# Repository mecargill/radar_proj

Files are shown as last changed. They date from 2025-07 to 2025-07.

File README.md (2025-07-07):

You can find a description of this radar project on https://mecargill.github.io/portfolio_page/.

Mcu_fmcw_manager is code for an STM32 f446. It buffers data from the ADC and sends it over SPI to the master (a raspberry pi in my case).
It also sends a triangle wave to the DAC.

Fmcw_pcb contains the KiCAD project in which I made the schematic and PCB for the radar.

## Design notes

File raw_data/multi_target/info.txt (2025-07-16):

I first took a baseline for 5s, then took a capture of a static corner reflector for 5s, then took a capture of me and shae moving forward and back at different distances for 25s
Turns out I messed up my pcb and made the data clip, so these data are kinda bad. I fixed it later

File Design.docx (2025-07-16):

# Operation

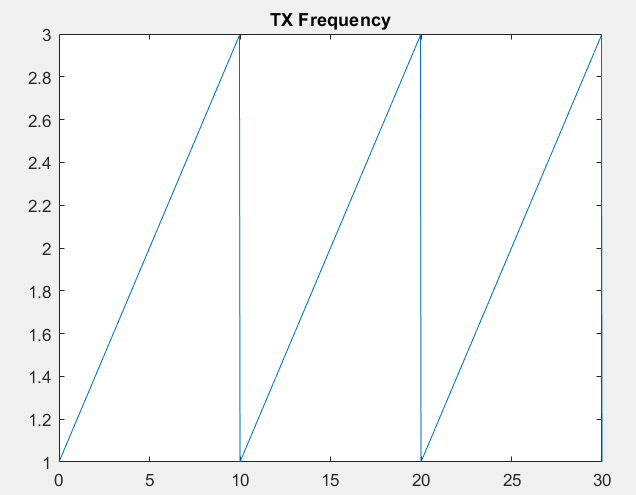
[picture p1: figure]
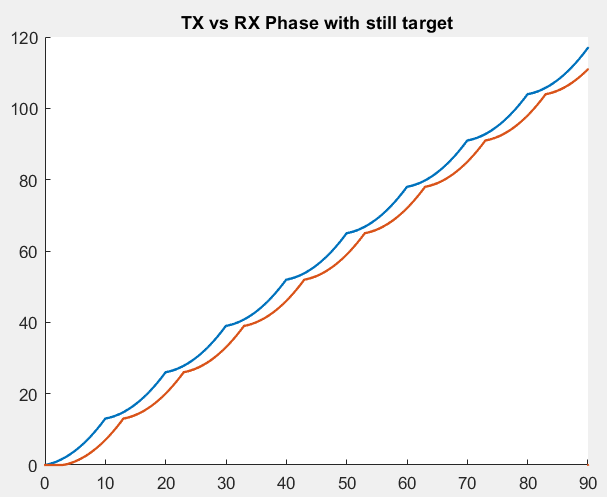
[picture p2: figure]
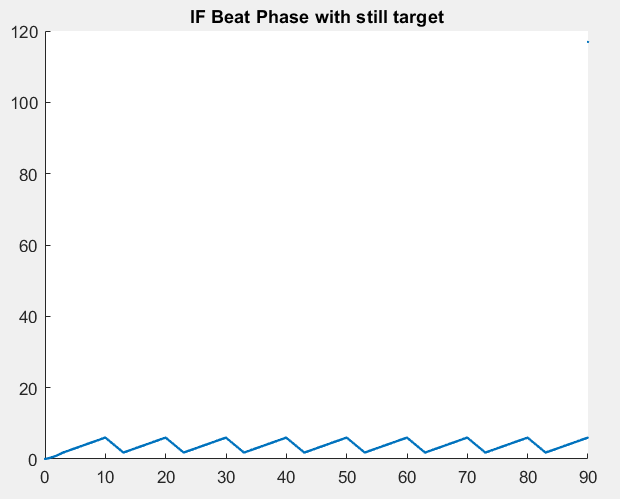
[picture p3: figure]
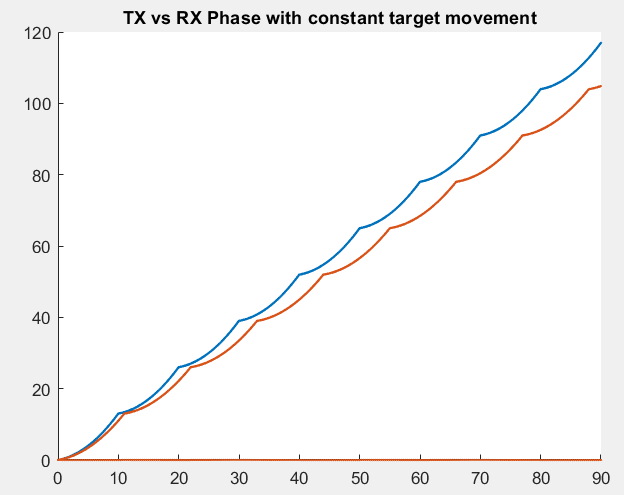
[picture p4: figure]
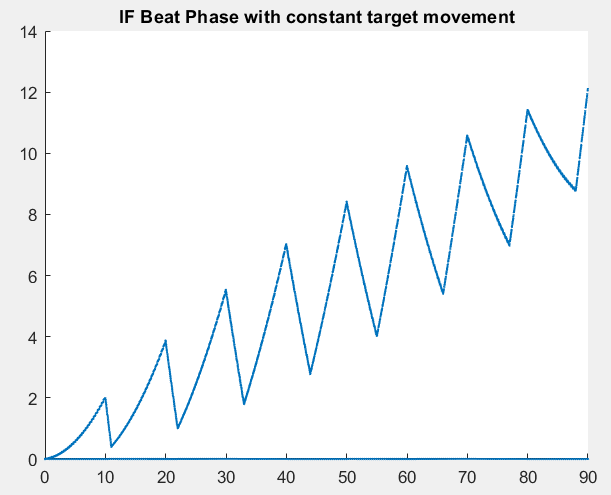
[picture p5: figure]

The TX signal is the scaled integral of the frequency function. The RX signal is a function where at a time t it equals the TX at a time t – d(t) where d(t) is the delay that the signal currently being received had to undergo due to the round trip time. Taking the fft of each cycle gives the slope. Taking the fft of that gives the slope of given points in each cycle, say the bottom, which under certain assumptions is linear (small delays, range is limited anyways).

# Target Specs

- FCC part 15 doesn’t consider CW applications… closest is digital modulation in part 15.247 – max conducted power 1W (30dBm) w max 6dbi antenna gain, so max 36dBm EIRP
- 2400 – 2483.5 GHz ISM band – low regulation, at worst will mess with wifi
- Max 6dbi antenna – keep it directional
- Use microcontroller and DAC (possibly built in) for ramp generation and buffering ADC output
- 500us chirp time, 80MHz sweep
- 10m range in normal operating conditions

# Part Options

1. Microcontroller
  a. STM32F745VGH6
    i. Hopefully this is enough
    ii. Has a couple dacs and adcs and prob enough power for FFT and stuff
  b. STM32H743VGT6
    i. More memory and power
    ii. 15$
  c. St link
    i. https://www.amazon.com/AITRIP-Emulator-Downloader-Programmer-STM32F103C8T6/dp/B0D22S8WVX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
2. DAC
  a. On MCU
3. VCO
  a. Crystek CVCO33BE-2400-2500
    i. 0-3VDC tuning
    ii. 2.4-2.5GHz
    iii. 55MHz/V sensitivity
    iv. +1dBm Typ output power
    v. -116 dBc/Hz at 100kHz offset
    vi. 25$
  b. MAX 2750
    i. 0.4-2.4V tuning
    ii. 2.4-2.5GHz
    iii. ~50MHz/V sensitivity
    iv. -3dBm output
    v. -95dBc/Hz at 100kHz offset
    vi. 9$
4. RF connections for pcb
  a. Sma to nM x2
    i. Cinch Connectivity 29 3840
      1. 9$
    ii. RF Industries RSA 3453 or 3478
      1. 10$
  b. Sma through hole x2
    i. Gradconn RFPC SMA 28 F
      1. 2$
  c. Sma m to m barrel
    i. RF solutions ADP-SMAM-SMAM90
      1. Right angle
      2. $5
5. Splitter
  a. Mini circuits ZX10-2-332-S
    i. 46$ Yikes
  b. BD 2626
    i. $2
  c. Make one yourself
    i. Bunch of resistors and stuff
    ii. 10$?
6. PA
  a. BeRex BG13D
    i. 21.5 dB gain
    ii. P1db 19
    iii. 3$
  b. Skyworks SKY65900-11
    i. 34dB gain
    ii. P1db 34 dBm
    iii. $2.5
7. Antenna
  a. FMANLP1009 x2
    i. 10 dBi gain
    ii. 50 deg beamwidth
    iii. 16$
    iv. Female n connector
  b. Make own
8. LNA
  a. https://www.digikey.com/en/products/filter/rf-amplifiers/860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
  b. Berex BL022A
    i. 17-18.5 dB gain 2.4GHz
    ii. 1.5-1.8 NF 2.4GHz
    iii. 3.50$
  c. Qorvo QPL9504
    i. 20-21dB gain 2.4GHz
    ii. ~0.5dB NF
    iii. No leads
    iv. 5$
9. Mixer
  a. MAX 2680
    i. 3$
    ii. Active -> -10-0 dBm LO input, and >-25dBm RF input
    iii. Not rated to output less than 10MHz
  b. ADL5801ACPZ-R7
    i. 15$
  c. LTC5548IUDB#TRPBF
    i. 25$
  d. TRF3705IRGER
  e. Mini Circuits ADE-3G+
    i. $7
    ii. Requires input and output match
    iii. Requires amplified LO
    iv. Overall an extra amp, attenuator, and matching net
  f. Analog AD8343
    i. $11
    ii. Requires output match
    iii. Active, -10dB LO
10. BPF
  a. Walsin RFBPF1608060AAT
    i. 2.4-2.5GHZ
    ii. Like $1 for all 3
    iii. Very small, like 0.8mm x 1mm
  b. Johansen 2450BP08A0100001T
    i. Same specs
    ii. Slightly bigger
  c. Taoglas DBP.2450.X.A.30
    i. 1 db more IL
    ii. Much bigger, way easier to solder
11. LPF
  a. Make one yourself
    i. Op amp and stuff
    ii. 2$?
12. ADC
  a. On MCU
13. Housing
  a. 3D print or ignore for now…

# Design

To choose the exact output power, we consider that we want as low power as possible (for less heat, oscillation, and saturation risk) while maintaining some amount of range ability. I would like around >=10m of range for a normal target (maybe a car w 10m^2 RCA).

Here, the rows are ranges (1, 5, 10, 15) m, and columns are (1, 10, 40) m^2 RCA. The power levels are conducted.

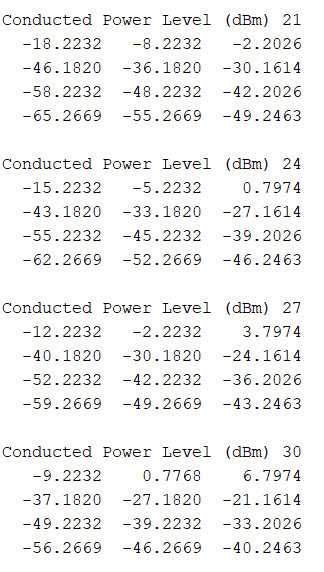
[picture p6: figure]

24-27 dBm conducted power works out. -45 dBm Pr I would estimate to be usable conservatively, given some common LNA and mixer specs. In the 0-2 dBm Pr situation, the mixer risks overloading. The overloading risks looks pretty low though, so we’ll just be careful to keep a good distance.

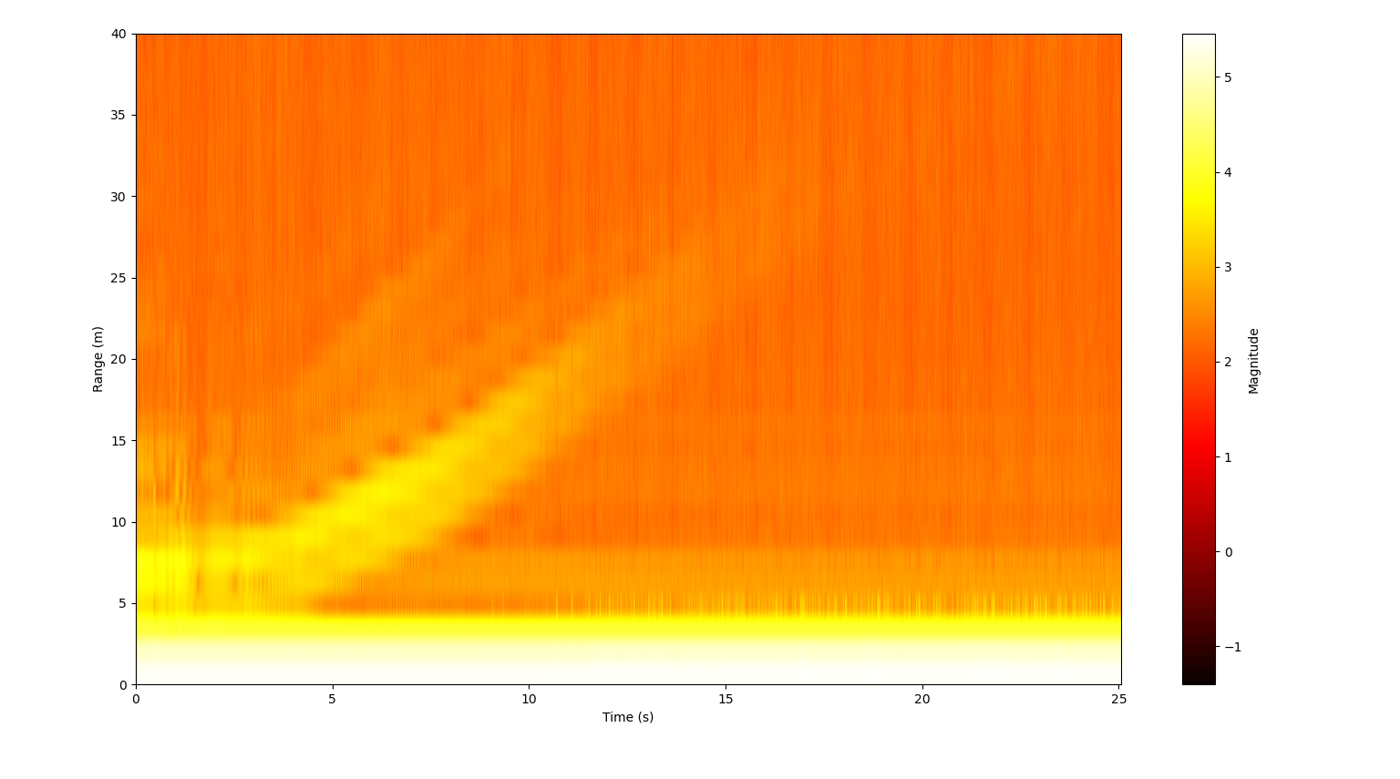
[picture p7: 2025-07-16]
figures/max_range.png

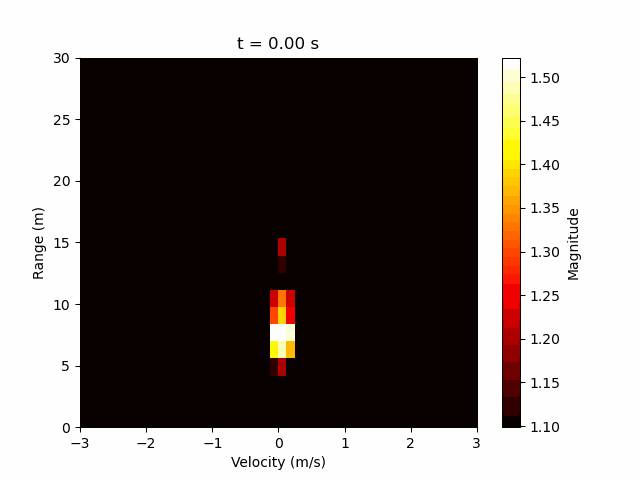
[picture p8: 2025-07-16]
figures/data_doppler_high_contrast.gif

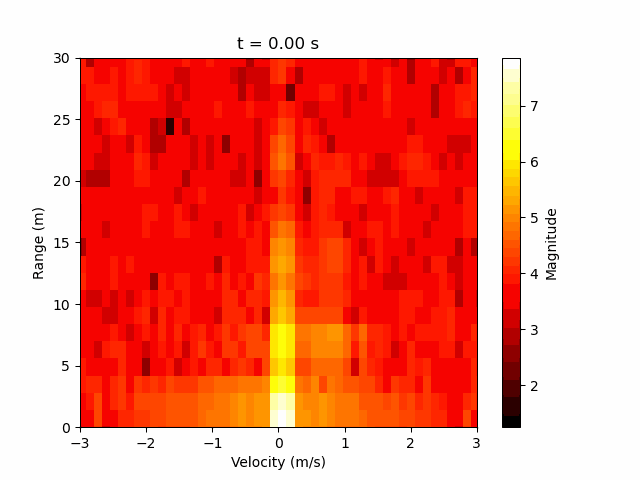
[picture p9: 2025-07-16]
figures/data_doppler.gif

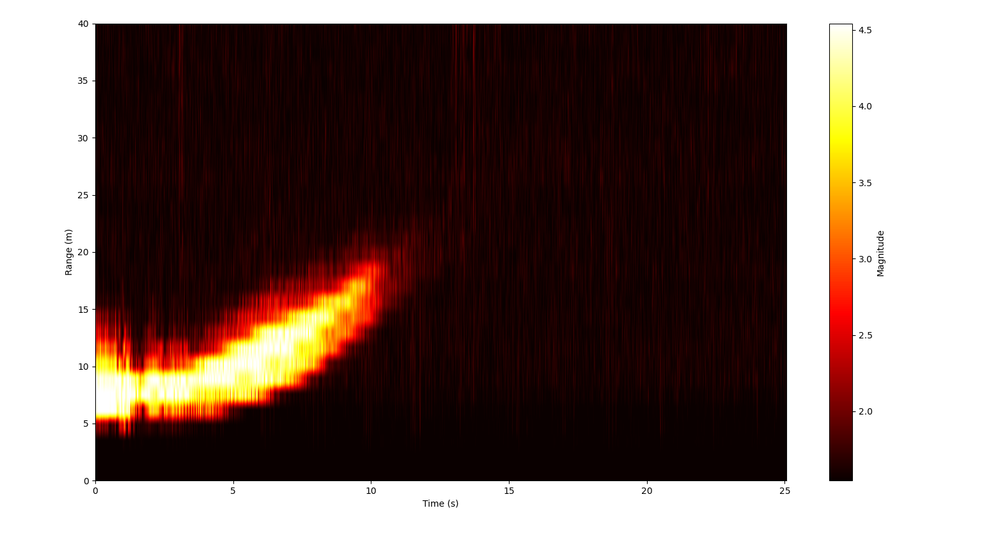
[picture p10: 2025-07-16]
figures/max_range_high_contrast.png

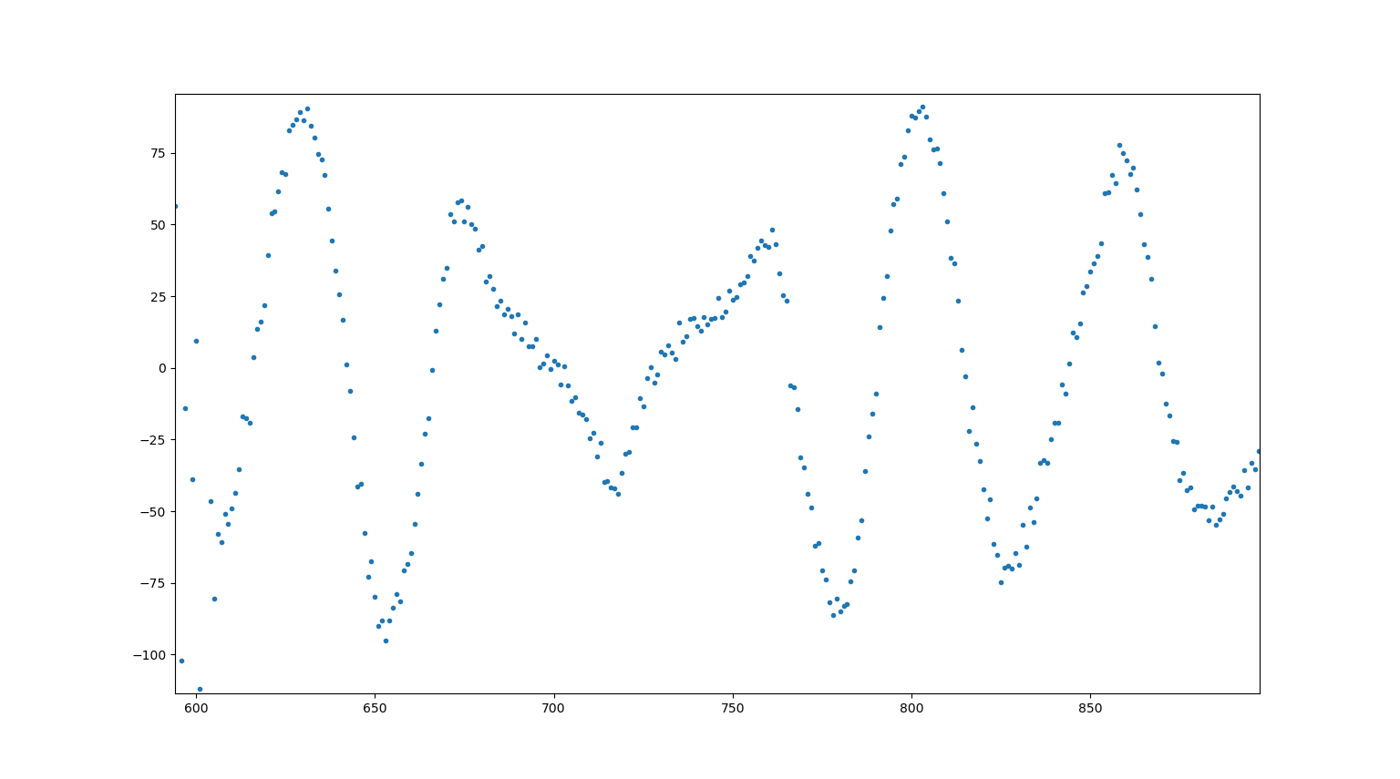
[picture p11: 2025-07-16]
figures/mirror_effect.png

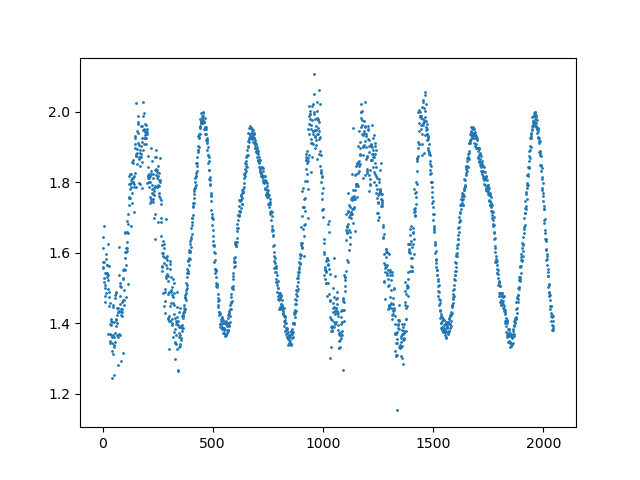
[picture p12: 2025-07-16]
figures/adc_corner_refl_2m.png

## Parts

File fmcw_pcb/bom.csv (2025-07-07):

Reference | Value | Datasheet | Footprint | Qty | DNP
AT1,AT4,AT5,AT7 | 10dB | http://industrial.panasonic.com/www-cgi/jvcr13pz.cgi?E+PZ+3+AOJ0002+EXB24AT6AR5X+7+WW | my_footprints:EXB24AT6AR5X | 4
AT2 | 1dB | http://industrial.panasonic.com/www-cgi/jvcr13pz.cgi?E+PZ+3+AOJ0002+EXB24AT6AR5X+7+WW | my_footprints:EXB24AT6AR5X | 1
AT3,AT6 | 6dB | http://industrial.panasonic.com/www-cgi/jvcr13pz.cgi?E+PZ+3+AOJ0002+EXB24AT6AR5X+7+WW | my_footprints:EXB24AT6AR5X | 2
BPF1,BPF2 | DEA202450BT-1275A1 | DEA202450BT-1275A1 | my_footprints:DEA-4_2P0X1P25 | 2
C1,C4,C12,C22,C24 | 1u | ~ | Capacitor_SMD:C_0805_2012Metric | 5
C2,C3,C10,C11 | 20p | ~ | Capacitor_SMD:C_0603_1608Metric | 4
C5,C13 | 10n | ~ | Capacitor_SMD:C_0805_2012Metric | 2
C6,C7 | 220p | ~ | Capacitor_SMD:C_0603_1608Metric | 2
C8,C27 | 0.1u | ~ | Capacitor_SMD:C_0805_2012Metric | 2
C9 | 1000p | ~ | Capacitor_SMD:C_0805_2012Metric | 1
C20 | 470u | ~ | Capacitor_THT:CP_Radial_D7.5mm_P2.50mm | 1
C21,C23 | 1n | ~ | Capacitor_SMD:C_0805_2012Metric | 2
C25,C26 | 10u | ~ | Capacitor_Tantalum_SMD:CP_EIA-6032-15_Kemet-U | 2
C34,C35 | 5.1p | ~ | Capacitor_SMD:C_0603_1608Metric | 2
C36 | 470n | ~ | Capacitor_SMD:C_0805_2012Metric | 1
FL1 | BPGE-252R+ | BPGE-252R+ | my_footprints:GE0805C-3_MNC | 1
GB1,GB2 | BGA616H6327XTSA1 | https://www.infineon.com/dgdl/Infineon-BGA616-DS-v02_01-en.pdf?fileId=db3a304314dca3890115419102bb163b | my_footprints:BGA616H6327XTSA1 | 2
J1 | usb |  | my_footprints:AMPHENOL_10118194-0001LF | 1
J2,J4,J5,J6 | EMPCB.SMAFSTJ.B.HT |  | my_footprints:sma_1.6mm | 4
J3 | MCU conn |  | Connector:FanPinHeader_1x04_P2.54mm_Vertical | 1
J7,J8 | DNI (sma) |  | my_footprints:sma_1.6mm | 2
L1,L2 | 39n | ~ | Inductor_SMD:L_0603_1608Metric | 2
L8 | 20n | ~ | Inductor_SMD:L_0603_1608Metric | 1
LDO1,OA1 | ~ |  | -- mixed values -- | 2
MIX1 | ADE-3G+ | ADE-3G+ | RF_Mini-Circuits:Mini-Circuits_CD542_LandPatternPL-052 | 1
PA1 | QPA9226TR13 | https://www.qorvo.com/products/d/da005895 | my_footprints:QPA9226TR13 | 1
R1 | 3k | ~ | Resistor_SMD:R_0805_2012Metric | 1
R2,R10 | 100 | ~ | Resistor_SMD:R_0805_2012Metric | 2
R3,R12,R14 | 10k | ~ | Resistor_SMD:R_0805_2012Metric | 3
R4 | 1k | ~ | Resistor_SMD:R_0805_2012Metric | 1
R5,R6,R8,R16 | 0 | -- mixed values -- | -- mixed values -- | 4
R9 | 62 | ~ | Resistor_SMD:R_0805_2012Metric | 1
R11,R15 | 16 | ~ | Resistor_SMD:R_0805_2012Metric | 2
R19 | DNI | ~ | Resistor_SMD:R_0805_2012Metric | 1
SPLT1 | SCN-2-27+ | SCN-2-27+ | Filter:Filter_Mini-Circuits_FV1206-1 | 1
SW1 | TX_EN | ~ | Connector_PinHeader_2.54mm:PinHeader_1x02_P2.54mm_Vertical | 1
TP1 | 5V | ~ | TestPoint:TestPoint_Pad_2.5x2.5mm | 1
TP2 | 3.3V | ~ | TestPoint:TestPoint_Pad_2.5x2.5mm | 1
TP3 | Tune | ~ | TestPoint:TestPoint_Pad_2.5x2.5mm | 1
TP4 | PA_DET | ~ | TestPoint:TestPoint_Pad_2.5x2.5mm | 1
TP5 | ADC_INP | ~ | TestPoint:TestPoint_Pad_2.5x2.5mm | 1
TP6 | IF | ~ | TestPoint:TestPoint_Pad_2.5x2.5mm | 1
VCO1 | MAX2750AUA_ |  | my_footprints:SOP65P490X110-8N | 1

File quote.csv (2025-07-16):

All transactions with DigiKey, including its affiliates, are subject to DigiKey’s Terms of Use and Conditions of Order | https://www.digikey.com/en/terms-and-conditions
Digi-Key Part Number | Manufacturer | Manufacturer Part Number | Requested Part Number | Description | Customer Reference | Quantity 1 | Unit Price 1 | Extended Price 1 | Minimum Release 1 | Minimum Order Quantity | Standard Pack | Availability | Pack Type | Manufacturer Lead Time | Country of Origin | RoHS Status | ECCN | HTSUS | Moisture Sensitivity Level (MSL) | Lead Free Status | REACH Status | US Import Tariff | Pricing Valid Through | Product Notes
497-STM32H743VGT6-ND | STMicroelectronics | STM32H743VGT6 | 497-STM32H743VGT6-ND | IC MCU 32BIT 1MB FLASH 100LQFP |  | 1 | 14.92 | $14.92 | 1 | 1 | 0 | 188 | Tray | 15 Weeks | Philippines | ROHS3 Compliant | 3A991A2 | 8542.31.0025 | 3 (168 Hours) | Not available | REACH Unaffected | N/A | 6/20/2025
MAX2750EUA+TCT-ND | Analog Devices Inc./Maxim Integrated | MAX2750EUA+T | MAX2750EUA+TCT-ND | IC OSC VOLT CNTRL 8-UMAX |  | 1 | 9.74 | $9.74 | 1 | 1 | 0 | 1940 | Cut Tape (CT) | 10 Weeks | Taiwan | ROHS3 Compliant | EAR99 | 8542.39.0060 | 1 (Unlimited) | Not available | REACH Unaffected | N/A | 6/20/2025
2072-RFPC-SMA28-F-ND | GCT (Gradconn) | RFPC-SMA28-F | 2072-RFPC-SMA28-F-ND | SMA VERTICAL PCB JACK |  | 7 | 1.73 | $12.11 | 1 | 1 | 0 | 1488 | Tray | 6 Weeks | Taiwan | ROHS3 Compliant | EAR99 | 8536.69.4010 | Not Applicable | Not available | - | N/A | 6/20/2025
ADP-SMAM-SMAM-ND | TE Connectivity Linx | ADP-SMAM-SMAM | ADP-SMAM-SMAM-ND | COAX ADAPT SMA TO SMA |  | 2 | 5.31 | $10.62 | 1 | 1 | 0 | 487 | Bulk | 7 Weeks | China | RoHS Compliant | EAR99 | 8536.69.4010 | 1 (Unlimited) | Lead free | REACH Unaffected | May apply on shipments to the U.S. | 6/20/2025
4770-BD2626CT-ND | BeRex Corp | BD2626 | 4770-BD2626CT-ND | 2.4-2.9GHZ, 2WAY SMT DIVIDER, SO |  | 1 | 2.13 | $2.13 | 1 | 1 | 1 | 3690 | Cut Tape (CT) | 26 Weeks | South Korea | ROHS3 Compliant | EAR99 | 8542.39.1000 | 1 (Unlimited) | Not available | REACH Affected | N/A | 6/20/2025
863-2136-1-ND | Skyworks Solutions Inc. | SKY65900-11 | 863-2136-1-ND | 28DBM 2GHZ PA IN 4X4 QFN |  | 1 | 2.39 | $2.39 | 1 | 1 | 1 | 2727 | Cut Tape (CT) | 15 Weeks | Malaysia | Unknown | 5A991G | 8542.33.0001 | 3 (168 Hours) | Not available | - | N/A | 6/20/2025
4770-BL022ACT-ND | BeRex Corp | BL022A | 4770-BL022ACT-ND | IC AMP 5G 50MHZ-6GHZ SOT89-3 |  | 1 | 3.51 | $3.51 | 1 | 1 | 0 | 2882 | Cut Tape (CT) | 26 Weeks | South Korea | ROHS3 Compliant | EAR99 | 8542.33.0001 | 1 (Unlimited) | Not available | REACH Affected | N/A | 6/20/2025
MAX2680EUT+CT-ND | Analog Devices Inc./Maxim Integrated | MAX2680EUT+T | MAX2680EUT+CT-ND | IC MXR 400MHZ-2.5GHZ DWN SOT23-6 |  | 1 | 3.03 | $3.03 | 1 | 1 | 1 | 502 | Cut Tape (CT) | 12 Weeks | Thailand | ROHS3 Compliant | EAR99 | 8542.39.0060 | 1 (Unlimited) | Not available | REACH Unaffected | N/A | 6/20/2025
931-1586-1-ND | Taoglas Limited | DBP.2450.X.A.30 | 931-1586-1-ND | RF FILTER BAND PASS 2.45GHZ 2SMD |  | 3 | 1.66 | $4.98 | 1 | 1 | 0 | 881 | Cut Tape (CT) | 11 Weeks | Taiwan | ROHS3 Compliant | EAR99 | 8504.50.8000 | 3 (168 Hours) | Lead free | REACH Unaffected | N/A | 6/20/2025
Total |  |  |  |  |  |  |  | $63.43

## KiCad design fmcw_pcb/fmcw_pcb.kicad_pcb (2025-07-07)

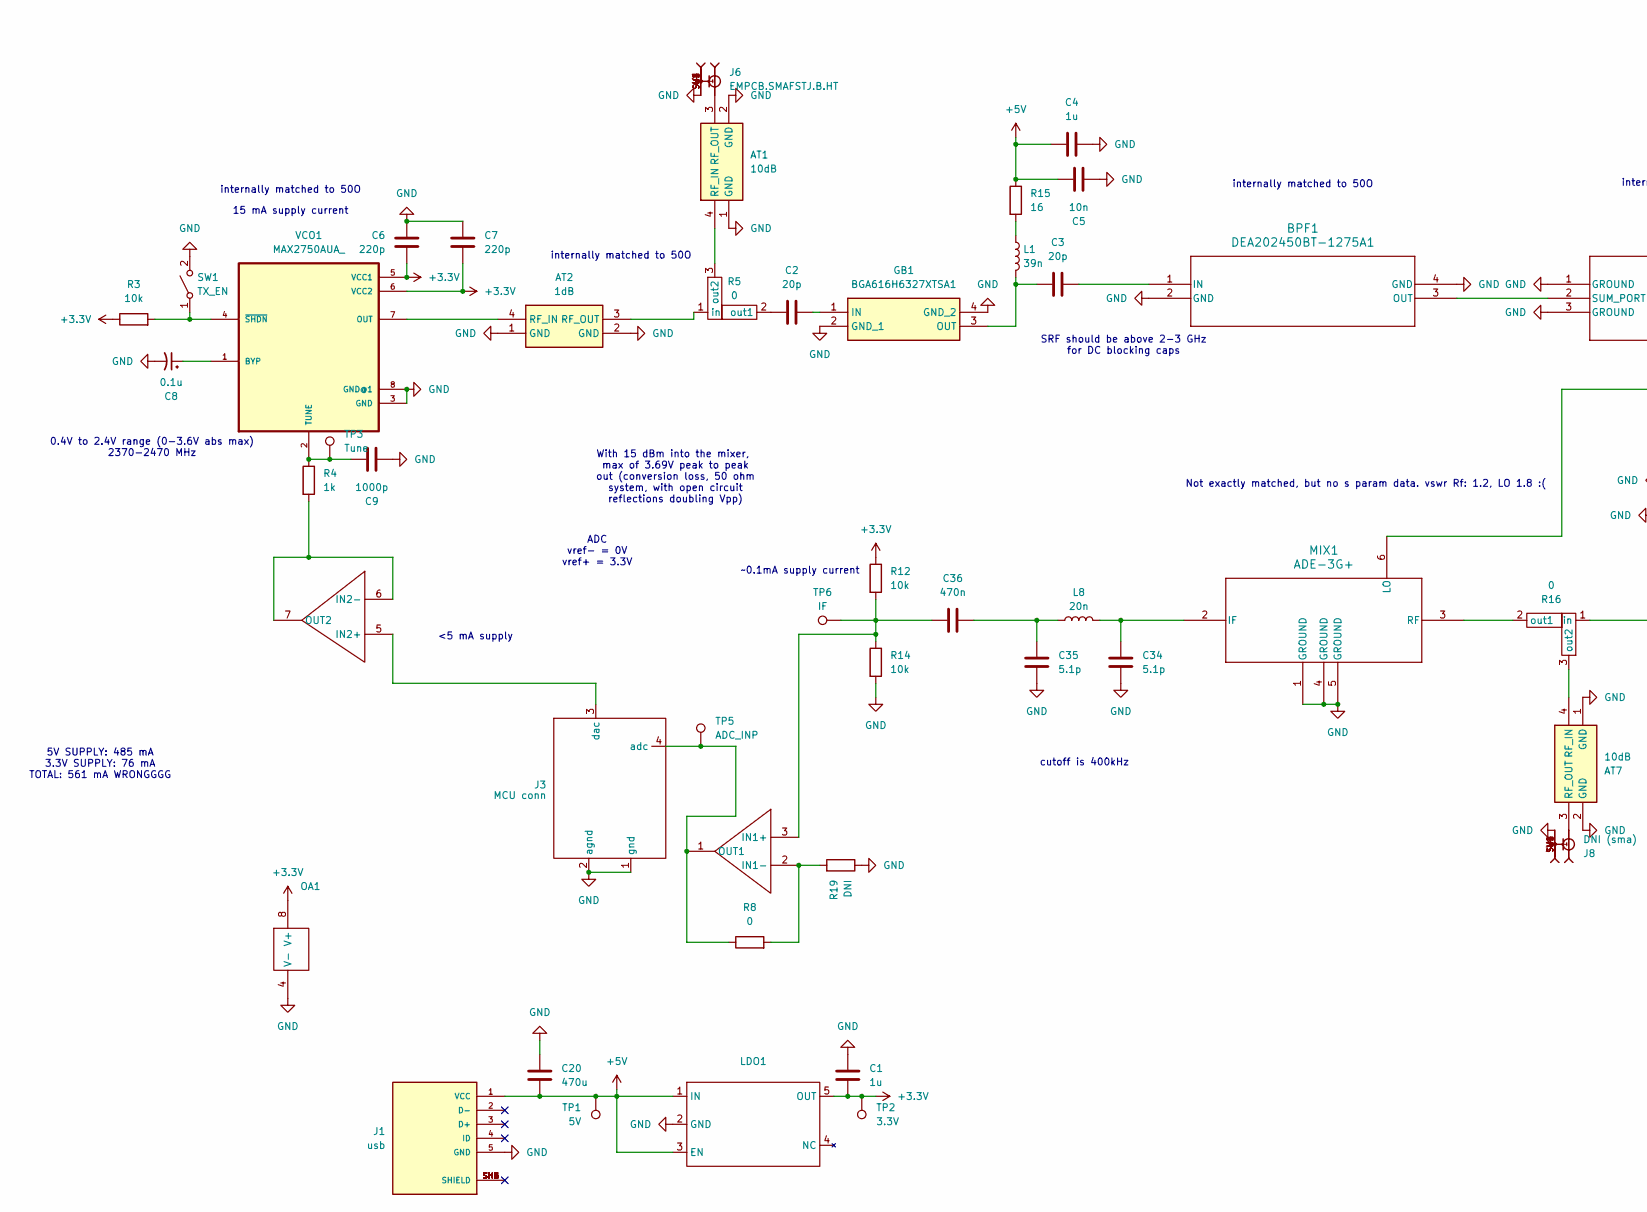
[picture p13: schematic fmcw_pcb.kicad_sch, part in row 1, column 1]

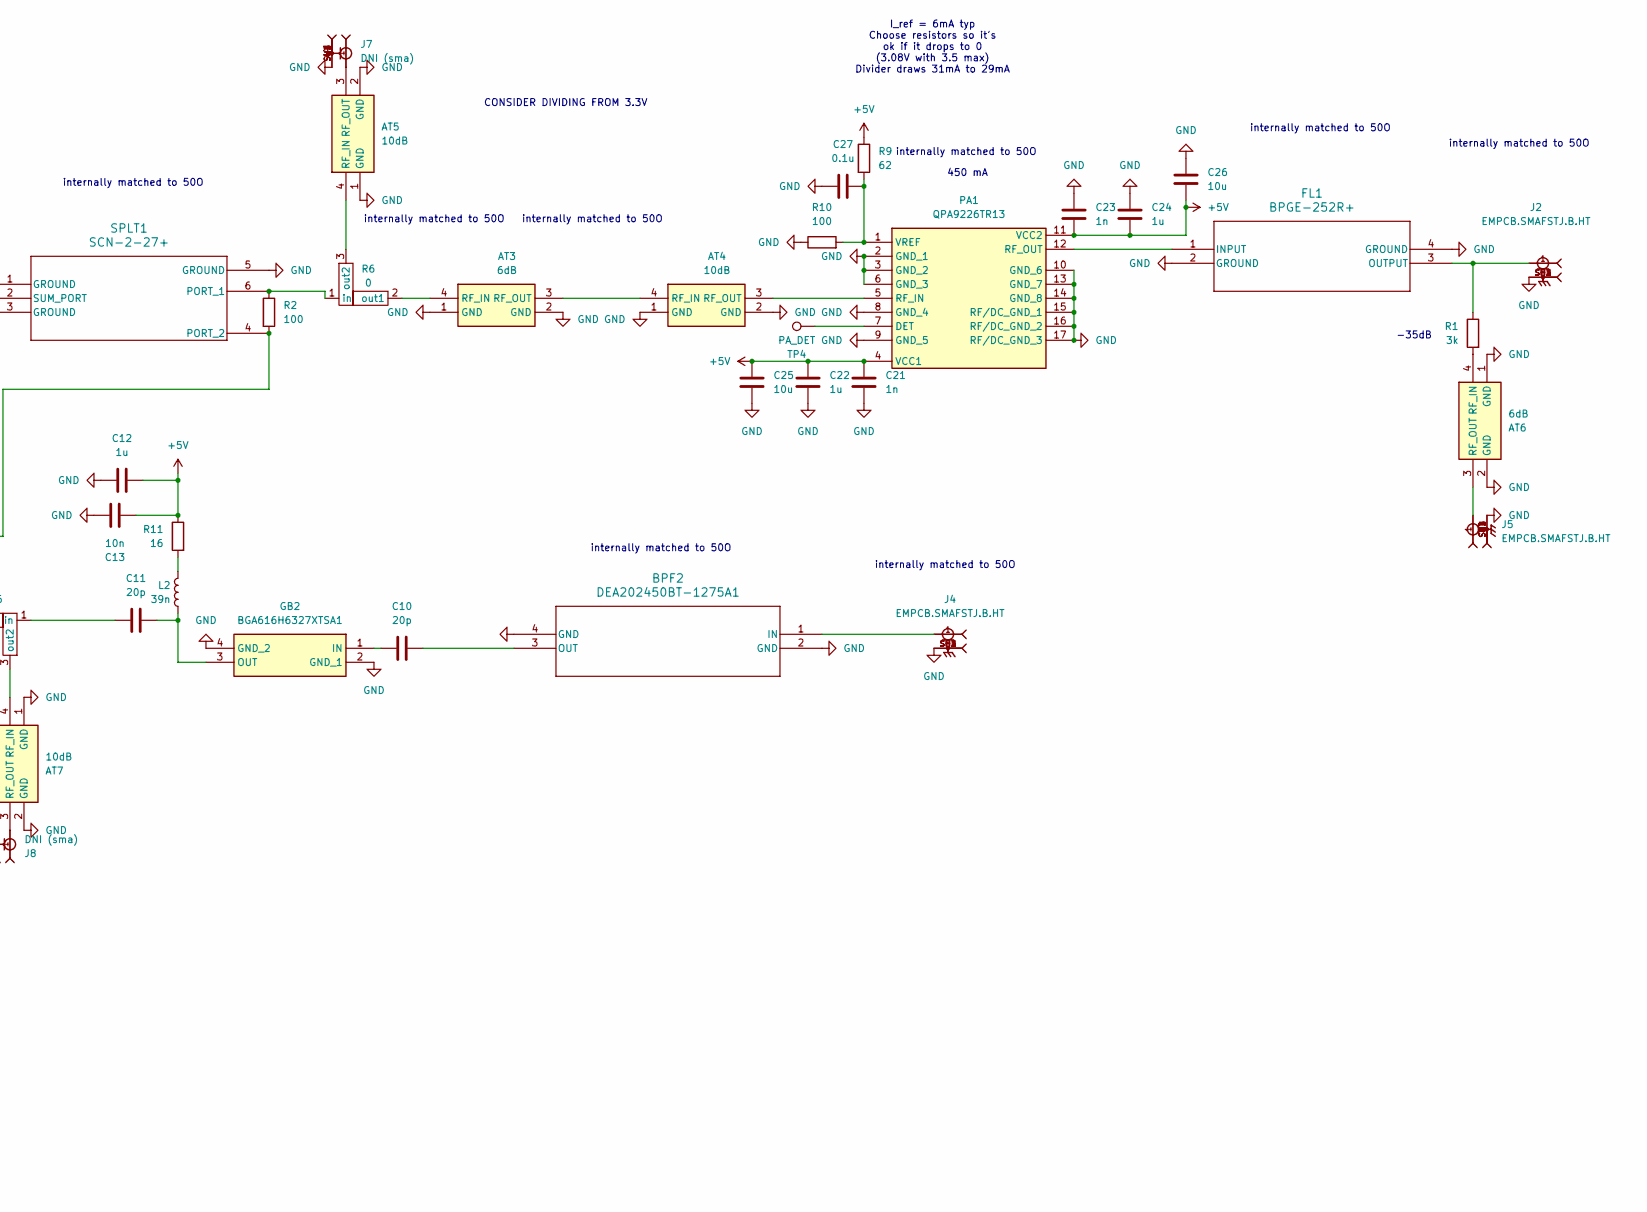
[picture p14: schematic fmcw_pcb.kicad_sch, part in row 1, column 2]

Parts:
AT1, AT4, AT5, AT7: 10dB; EXB24AT6AR5X; Manufacturer_Part_Number EXB-24AT6AR5X; Mouser Part Number 667-EXB-24AT6AR5X
AT2: 1dB; EXB24AT6AR5X; Manufacturer_Part_Number EXB-24AT6AR5X; Mouser Part Number 667-EXB-24AT6AR5X
AT3, AT6: 6dB; EXB24AT6AR5X; Manufacturer_Part_Number EXB-24AT6AR5X; Mouser Part Number 667-EXB-24AT6AR5X
BPF1, BPF2: DEA202450BT-1275A1; DEA-4_2P0X1P25
C1, C4, C12, C22, C24: 1u; C_0805_2012Metric
C2, C3, C10, C11: 20p; C_0603_1608Metric
C5, C13: 10n; C_0805_2012Metric
C6, C7: 220p; C_0603_1608Metric
C8, C27: 0.1u; C_0805_2012Metric
C9: 1000p; C_0805_2012Metric
C20: 470u; CP_Radial_D7.5mm_P2.50mm
C21, C23: 1n; C_0805_2012Metric
C25, C26: 10u; CP_EIA-6032-15_Kemet-U
C34, C35: 5.1p; C_0603_1608Metric
C36: 470n; C_0805_2012Metric
FL1: BPGE-252R+; GE0805C-3_MNC
GB1, GB2: BGA616H6327XTSA1; Manufacturer_Part_Number BGA616H6327XTSA1; Mouser Part Number 726-BGA616H6327XTSA1
J1: usb; AMPHENOL_10118194-0001LF; PARTREV D
J2, J4, J5, J6: EMPCB.SMAFSTJ.B.HT; sma_1.6mm; DigiKey_Part_Number 931-1175-ND
J3: MCU conn; FanPinHeader_1x04_P2.54mm_Vertical
J7, J8: DNI (sma); sma_1.6mm; DigiKey_Part_Number 931-1175-ND
L1, L2: 39n; L_0603_1608Metric
L8: 20n; L_0603_1608Metric
LDO1: SOT95P280X145-5N(ldo)
MIX1: ADE-3G+; Mini-Circuits_CD542_LandPatternPL-052
OA1: SOT65P280X110-8N(op_amp)
PA1: QPA9226TR13; Mouser Part Number 772-QPA9226TR13
R1: 3k; R_0805_2012Metric
R2, R10: 100; R_0805_2012Metric
R3, R12, R14: 10k; R_0805_2012Metric
R4: 1k; R_0805_2012Metric
R5, R6, R16: 0; 2way_jumper
R8: 0; R_0805_2012Metric
R9: 62; R_0805_2012Metric
R11, R15: 16; R_0805_2012Metric
R19: DNI; R_0805_2012Metric
SPLT1: SCN-2-27+; Filter_Mini-Circuits_FV1206-1
SW1: TX_EN; PinHeader_1x02_P2.54mm_Vertical
TP1: 5V; TestPoint_Pad_2.5x2.5mm
TP2: 3.3V; TestPoint_Pad_2.5x2.5mm
TP3: Tune; TestPoint_Pad_2.5x2.5mm
TP4: PA_DET; TestPoint_Pad_2.5x2.5mm
TP5: ADC_INP; TestPoint_Pad_2.5x2.5mm
TP6: IF; TestPoint_Pad_2.5x2.5mm
VCO1: MAX2750AUA_; SOP65P490X110-8N; DigiKey_Part_Number MAX2750AUA+-ND

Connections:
+3.3V: C1.2, C6.2, C7.2, LDO1.5 (OUT), OA1.8 (V+), R3.1, R12.1, TP2.1, VCO1.5 (VCC1), VCO1.6 (VCC2); also elsewhere on the board
+5V: C4.1, C5.1, C12.1, C13.1, C20.1, C21.1, C22.1, C23.2, C24.2, C25.1, C26.2, J1.1 (VCC), LDO1.1 (IN), LDO1.3 (EN), PA1.4 (VCC1), PA1.11 (VCC2), R9.1, R11.1, R15.1, TP1.1; also elsewhere on the board
GND: AT1.1 (GND), AT1.2 (GND), AT2.1 (GND), AT2.2 (GND), AT3.1 (GND), AT3.2 (GND), AT4.1 (GND), AT4.2 (GND), AT5.1 (GND), AT5.2 (GND), AT6.1 (GND), AT6.2 (GND), AT7.1 (GND), AT7.2 (GND), BPF1.2 (GND), BPF1.4 (GND), BPF2.2 (GND), BPF2.4 (GND), C1.1, C4.2, C5.2, C6.1, C7.1, C8.2, C9.2, C12.2, C13.2, C20.2, C21.2, C22.2, C23.1, C24.1, C25.2, C26.1, C27.1, C34.1, C35.1, FL1.2 (GROUND), FL1.4 (GROUND), GB1.2 (GND_1), GB1.4 (GND_2), GB2.2 (GND_1), GB2.4 (GND_2), J1.5 (GND), J2.SH1, J2.SH2, J2.SH3, J2.SH4, J3.1 (gnd), J3.2 (agnd), J4.SH1, J4.SH2, J4.SH3, J4.SH4, J5.SH1, J5.SH2, J5.SH3, J5.SH4, J6.SH1, J6.SH2, J6.SH3, J6.SH4, J7.SH1, J7.SH2, J7.SH3, J7.SH4, J8.SH1, J8.SH2, J8.SH3, J8.SH4, LDO1.2 (GND), MIX1.1 (GROUND), MIX1.4 (GROUND), MIX1.5 (GROUND), OA1.4 (V-), PA1.2 (GND_1), PA1.3 (GND_2), PA1.6 (GND_3), PA1.8 (GND_4), PA1.9 (GND_5), PA1.10 (GND_6), PA1.13 (GND_7), PA1.14 (GND_8), PA1.15 (RF/DC_GND_1), PA1.16 (RF/DC_GND_2), PA1.17 (RF/DC_GND_3), R10.1, R14.2, R19.1, SPLT1.1 (GROUND), SPLT1.3 (GROUND), SPLT1.5 (GROUND), SW1.2 (B), VCO1.3 (GND), VCO1.8 (GND@1)
unnamed: AT1.4 (RF_IN), R5.3 (out2)
unnamed: AT1.3 (RF_OUT), J6.1
unnamed: AT2.4 (RF_IN), VCO1.7 (OUT)
unnamed: AT2.3 (RF_OUT), R5.1 (in)
unnamed: AT3.4 (RF_IN), R6.2 (out1)
unnamed: AT3.3 (RF_OUT), AT4.4 (RF_IN)
unnamed: AT4.3 (RF_OUT), PA1.5 (RF_IN)
unnamed: AT5.4 (RF_IN), R6.3 (out2)
unnamed: AT5.3 (RF_OUT), J7.1
unnamed: AT6.4 (RF_IN), R1.2
unnamed: AT6.3 (RF_OUT), J5.1
unnamed: AT7.4 (RF_IN), R16.3 (out2)
unnamed: AT7.3 (RF_OUT), J8.1
unnamed: BPF1.1 (IN), C3.2
unnamed: BPF1.3 (OUT), SPLT1.2 (SUM_PORT)
unnamed: BPF2.1 (IN), J4.1
unnamed: BPF2.3 (OUT), C10.1
unnamed: C35.2, C36.2, L8.1
unnamed: FL1.1 (INPUT), PA1.12 (RF_OUT)
unnamed: FL1.3 (OUTPUT), J2.1, R1.1
unnamed: C2.2, GB1.1 (IN)
unnamed: C3.1, GB1.3 (OUT), L1.2
unnamed: C10.2, GB2.1 (IN)
unnamed: C11.1, GB2.3 (OUT), L2.2
unnamed 27: J3.4 (adc), OA1.1 (OUT1), R8.1, TP5.1; also elsewhere on the board
unnamed: J3.3 (dac), OA1.5 (IN2+)
unnamed: L1.1, R15.2
unnamed: L2.1, R11.2
unnamed: C34.2, L8.2, MIX1.2 (IF)
unnamed: MIX1.6 (LO), R2.2, SPLT1.4 (PORT_2)
unnamed: MIX1.3 (RF), R16.2 (out1)
unnamed 34: C36.1, OA1.3 (IN1+), R12.2, R14.1, TP6.1; also elsewhere on the board
unnamed: OA1.2 (IN1-), R8.2, R19.2
unnamed: OA1.6 (IN2-), OA1.7 (OUT2), R4.2
unnamed 37: PA1.7 (DET), TP4.1; also elsewhere on the board
unnamed: C27.2, PA1.1 (VREF), R9.2, R10.2
unnamed: C2.1, R5.2 (out1)
unnamed: R2.1, R6.1 (in), SPLT1.6 (PORT_1)
unnamed: C11.2, R16.1 (in)
unnamed: R3.2, SW1.1 (A), VCO1.4 (~SHDN)
unnamed: C8.1, VCO1.1 (BYP)
unnamed 44: C9.1, R4.1, TP3.1, VCO1.2 (TUNE); also elsewhere on the board

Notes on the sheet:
internally matched to 50O
Not exactly matched, but no s param data. vswr Rf: 1.2, LO 1.8 :(
I_ref = 6mA typ Choose resistors so it's ok if it drops to 0 (3.08V with 3.5 max) Divider draws 31mA to 29mA
With 15 dBm into the mixer, max of 3.69V peak to peak out (conversion loss, 50 ohm system, with open circuit reflections doubling Vpp)
<5 mA supply
cutoff is 400kHz
0.4V to 2.4V range (0-3.6V abs max) 2370-2470 MHz
450 mA
ADC vref- = 0V vref+ = 3.3V
~0.1mA supply current
CONSIDER DIVIDING FROM 3.3V
15 mA supply current
-35dB
SRF should be above 2-3 GHz for DC blocking caps
5V SUPPLY: 485 mA 3.3V SUPPLY: 76 mA TOTAL: 561 mA WRONGGGG

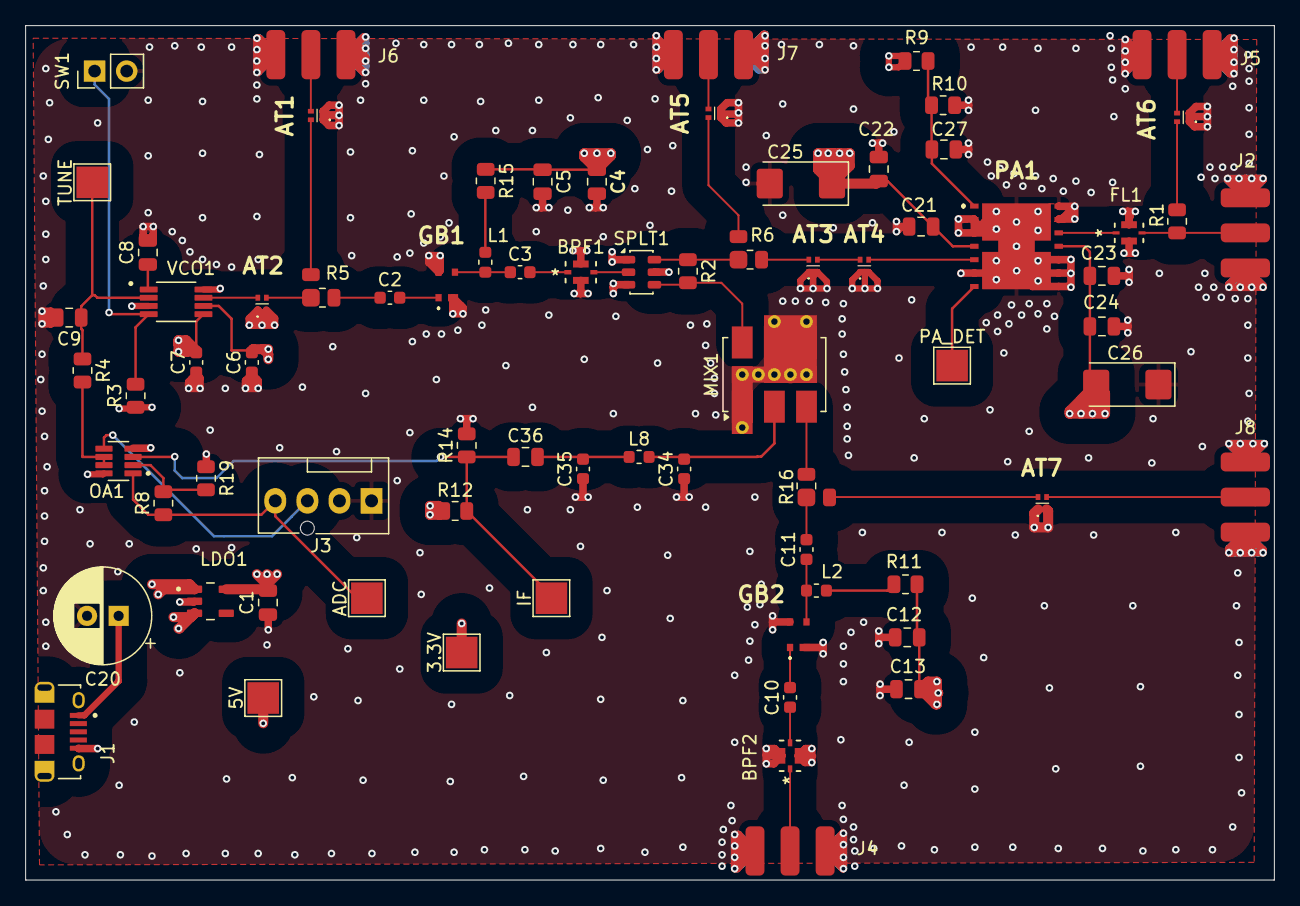
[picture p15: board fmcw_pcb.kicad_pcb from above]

Board: 4 copper layers, 98.8 x 67.6 mm, 75 parts (0 on the bottom side), 45 nets.

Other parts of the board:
3.3V: 3.3V; TestPoint_Pad_2.5x2.5mm
5V: 5V; TestPoint_Pad_2.5x2.5mm
ADC: ADC_INP; TestPoint_Pad_2.5x2.5mm
IF: IF; TestPoint_Pad_2.5x2.5mm
PA_DET: PA_DET; TestPoint_Pad_2.5x2.5mm
TUNE: Tune; TestPoint_Pad_2.5x2.5mm

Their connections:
+3.3V: 3.3V.1; also elsewhere on the board
+5V: 5V.1; also elsewhere on the board
unnamed 27: ADC.1; also elsewhere on the board
unnamed 34: IF.1; also elsewhere on the board
unnamed 37: PA_DET.1; also elsewhere on the board
unnamed 44: TUNE.1; also elsewhere on the board

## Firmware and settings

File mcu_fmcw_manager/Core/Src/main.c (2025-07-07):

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
/* Includes ------------------------------------------------------------------*/
#include "main.h"
#include "adc.h"
#include "dac.h"
#include "dma.h"
#include "spi.h"
#include "tim.h"
#include "usart.h"
#include "gpio.h"


/* USER CODE BEGIN PV */
uint16_t buffer[PI_SPI_LENGTH*2];
uint16_t* halfway_pt = buffer + PI_SPI_LENGTH;

uint16_t tune[2000];
/* USER CODE END PV */

void SystemClock_Config(void);
/**
  * @brief  The application entry point.
  * @retval int
  */
int main(void)
{

  /* USER CODE BEGIN 1 */
	//initialize  buffers
	//sized such that a trigger under 1 MHz will let us sweep 0.4 to 2.4V in ~0.5-1ms
	for(uint16_t i = 0; i < 579*2; i++) {

		if(i < 579) {
			tune[i] = 941 + 3*i;
		} else {
			tune[i] = 2679 - 3*(i - 579);
		}


	}


  /* USER CODE END 1 */

  /* MCU Configuration--------------------------------------------------------*/

  /* Reset of all peripherals, Initializes the Flash interface and the Systick. */
  HAL_Init();

  /* Configure the system clock */
  SystemClock_Config();

  /* Initialize all configured peripherals */
  MX_GPIO_Init();
  MX_DMA_Init();
  MX_ADC1_Init();
  MX_SPI2_Init();
  MX_USART2_UART_Init();
  MX_DAC_Init();
  MX_TIM6_Init();
  /* USER CODE BEGIN 2 */
  for(int i = 0; i < 12; i++) {
  	  HAL_GPIO_TogglePin(GPIOC, GPIO_PIN_10);
  	  HAL_Delay(250);
    }


  //buffer decays to ptr, call start adc dma on adc1
  HAL_ADC_Start_DMA(&hadc1, (uint32_t*) buffer, PI_SPI_LENGTH*2);
  HAL_DAC_Start_DMA(&hdac, DAC_CHANNEL_1, (uint32_t*) tune, 579*2, DAC_ALIGN_12B_R);
  //84/118 = 0.711MHz timer
  HAL_TIM_Base_Start(&htim6);



  /* USER CODE END 2 */

  /* Infinite loop */
  /* USER CODE BEGIN WHILE */
  while (1)
  {

    /* USER CODE END WHILE */

    /* USER CODE BEGIN 3 */
  }
  /* USER CODE END 3 */
}

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
/* USER CODE BEGIN 4 */

void HAL_ADC_ConvHalfCpltCallback(ADC_HandleTypeDef* hadc)
{
    if (hadc->Instance == ADC1)
    {
        // push first half of buffer to spi2
    	buffer[0] = 100*256+1;
		HAL_SPI_Transmit_DMA(&hspi2, (uint8_t*) buffer, PI_SPI_LENGTH);

    }
}

void HAL_ADC_ConvCpltCallback(ADC_HandleTypeDef* hadc)
{
    if (hadc->Instance == ADC1)
    {
        // Second half of adc_buffer is ready, push to spi2
    	halfway_pt[0] = 100*256+1;
    	HAL_SPI_Transmit_DMA(&hspi2, (uint8_t*) halfway_pt, PI_SPI_LENGTH);


  }
}


/* USER CODE END 4 */
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


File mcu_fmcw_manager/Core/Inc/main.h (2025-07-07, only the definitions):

#define B1_Pin GPIO_PIN_13
#define B1_GPIO_Port GPIOC
#define USART_TX_Pin GPIO_PIN_2
#define USART_TX_GPIO_Port GPIOA
#define USART_RX_Pin GPIO_PIN_3
#define USART_RX_GPIO_Port GPIOA
#define LD2_Pin GPIO_PIN_5
#define LD2_GPIO_Port GPIOA
#define TMS_Pin GPIO_PIN_13
#define TMS_GPIO_Port GPIOA
#define TCK_Pin GPIO_PIN_14
#define TCK_GPIO_Port GPIOA
#define SWO_Pin GPIO_PIN_3
#define SWO_GPIO_Port GPIOB
#define PI_SPI_LENGTH 2048

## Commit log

2025-07-07 Add folders
    [assembly_guide.csv, bom.csv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]
2025-07-14 Add rest of design files
    [quote.csv]

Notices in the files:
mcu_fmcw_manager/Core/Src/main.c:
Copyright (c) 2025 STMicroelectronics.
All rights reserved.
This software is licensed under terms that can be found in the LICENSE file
